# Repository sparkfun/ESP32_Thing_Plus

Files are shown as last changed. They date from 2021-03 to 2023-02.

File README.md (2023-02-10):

SparkFun ESP32 Thing Plus
========================================

SparkFun ESP32 Thing Plus (https://www.sparkfun.com/products/15663)

[*SparkFun ESP32 Thing Plus (WRL-15663)*](https://www.sparkfun.com/products/15663)

The [SparkFun ESP32 Thing Plus](https://www.sparkfun.com/products/15663) is a comprehensive development platform for [Espressif's ESP32](https://espressif.com/en/products/hardware/esp32/overview). Like the 8266 and ESP32 Thing, the ESP32 Thing Plus is a **WiFi**-compatible microcontroller with support for **Bluetooth low-energy** (i.e BLE, BT4.0, Bluetooth Smart), a Qwiic adapter, and 21 I/O pins. Add to that a rich set of peripherals ranging from capacitive touch sensors, SD card interface, Ethernet, high-speed SPI, UART, I2S and I<sup>2</sup>C.

Upgraded and easy to use, the Esp32 Thing Plus will help make it the foundation of IoT and connected projects for many years to come.

Repository Contents
-------------------

* **/Hardware** - Eagle design files (.brd, .sch)
* **/Production** - Production panel files (.brd)

Documentation
--------------
* **[Hookup Guide](https://learn.sparkfun.com/tutorials/esp32-thing-plus-hookup-guide)** - Basic hookup guide for the ESP32 Thing Plus.
* **[SparkFun Fritzing repo](https://github.com/sparkfun/Fritzing_Parts)** - Fritzing diagrams for SparkFun products.
* **[SparkFun Graphical Datasheets](https://github.com/sparkfun/Graphical_Datasheets)** -Graphical Datasheets for various SparkFun products.

Product Versions
----------------
* [WRL-15663](https://www.sparkfun.com/products/15663)- v2.0, Slight hardware update that includes a 10&ohm; series resistor between VUSB and CP2102
* [WRL-14689](https://www.sparkfun.com/products/14689)- v1.0, Initial Release

License Information
-------------------

This product is _**open source**_! 

Please review the LICENSE.md file for license information. 

If you have any questions or concerns on licensing, please contact technical support on our [SparkFun forums](https://forum.sparkfun.com/viewforum.php?f=152).

Distributed as-is; no warranty is given.

- Your friends at SparkFun.

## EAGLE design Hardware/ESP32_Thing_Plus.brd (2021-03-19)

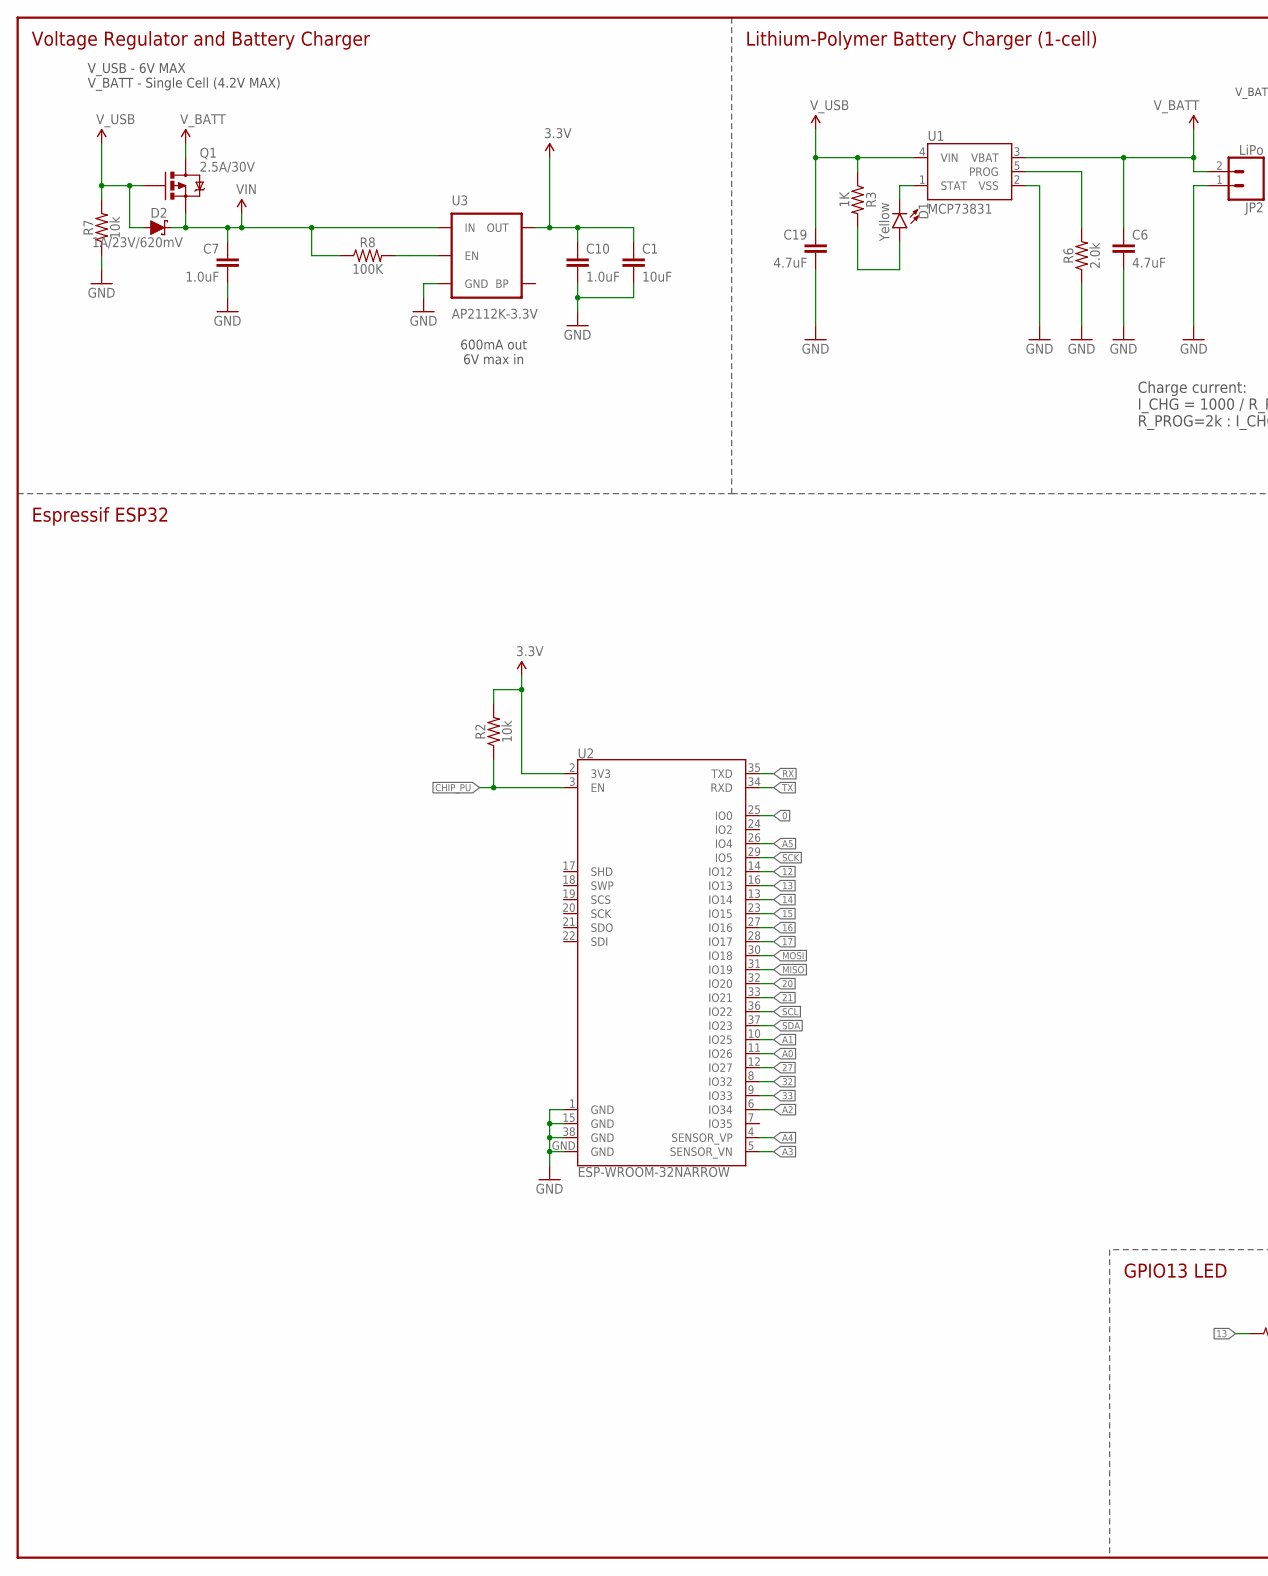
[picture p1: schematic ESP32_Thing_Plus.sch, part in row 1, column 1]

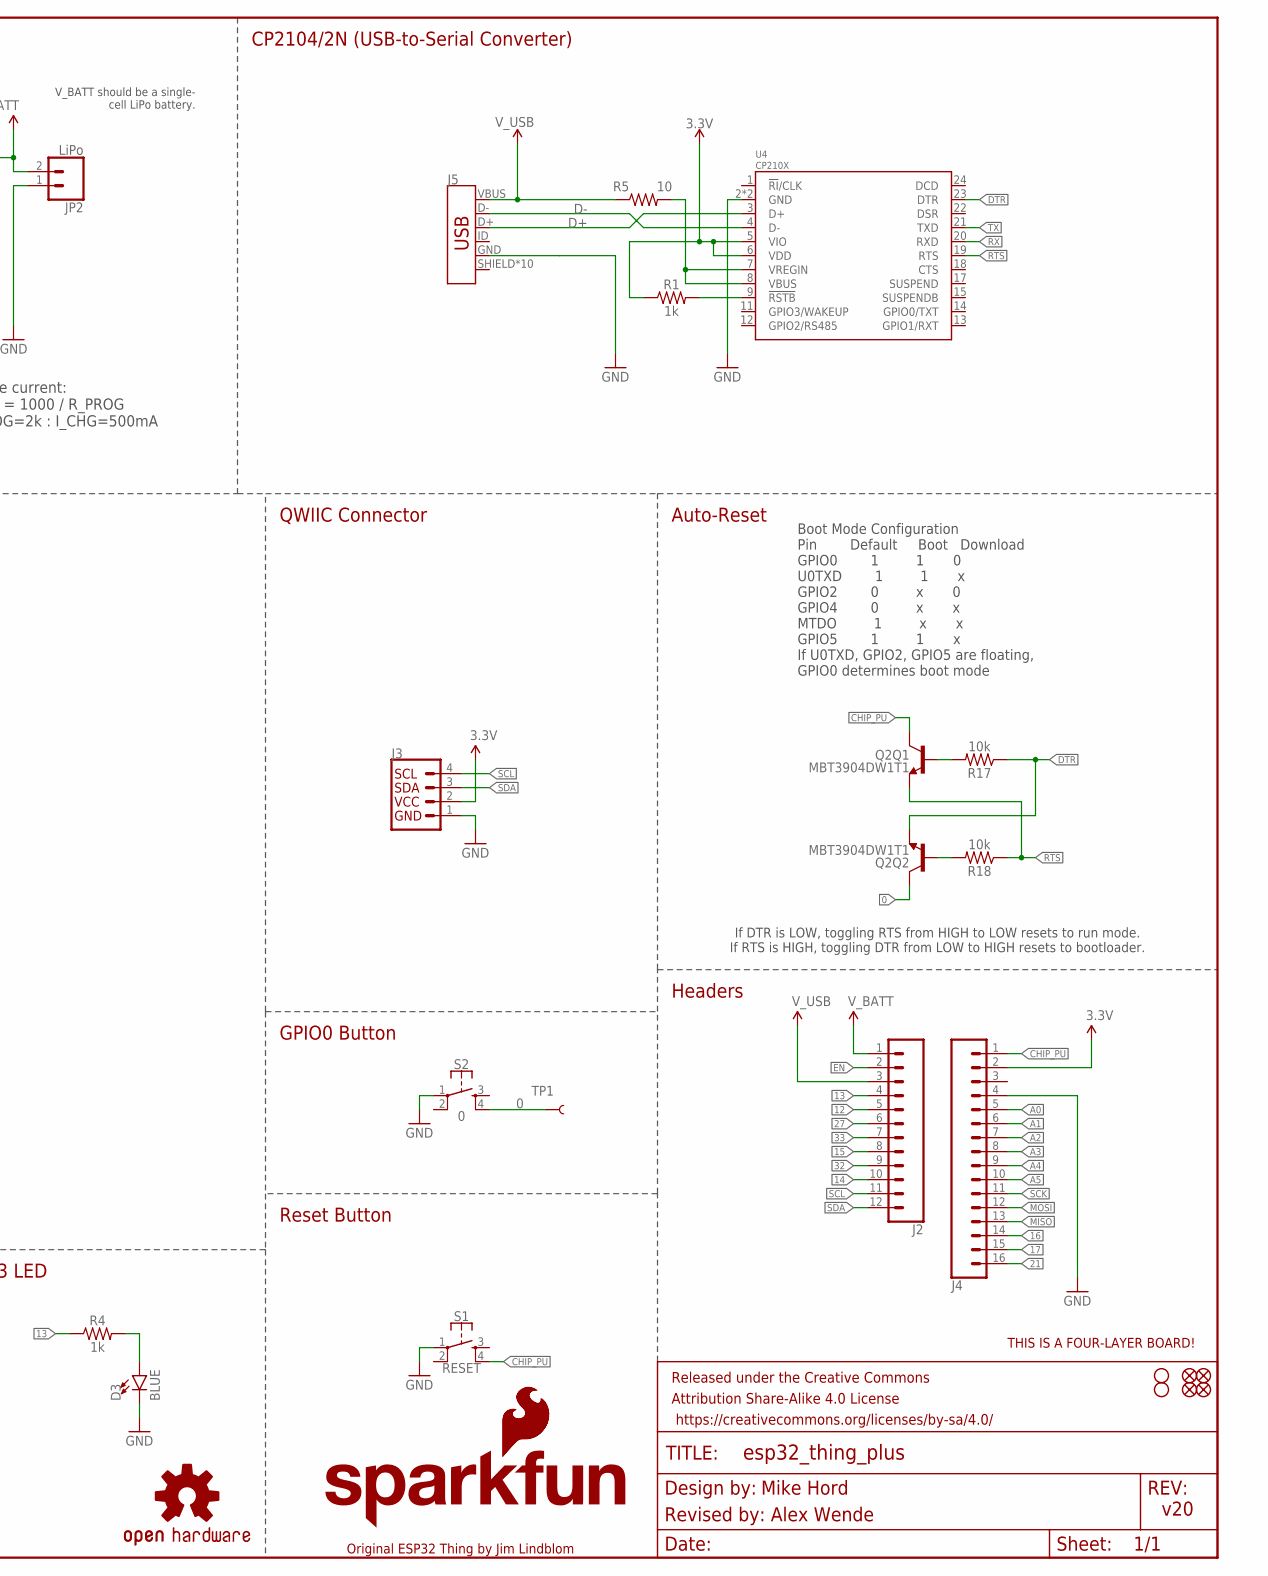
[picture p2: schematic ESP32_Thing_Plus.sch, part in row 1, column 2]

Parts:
C1: 10uF; 0603
C6, C19: 4.7uF; 0603
C7: 1.0uF; 0603
C10: 1.0uF; 0402
D1: Yellow; LED-0603
D2: 1A/23V/620mV; SOD-323
D3: BLUE; LED-0603
FD1, FD2, FD3, FD4: FIDUCIALUFIDUCIAL; FIDUCIAL-MICRO
FRAME1: FRAME-LEDGER; CREATIVE_COMMONS
H1, H2: STAND-OFFTIGHT; STAND-OFF-TIGHT
J2: CONN_12SM_SQ_NO_SILK; 1X12_SM_SQ_NOSILK
J3: QWIIC_CONNECTORJS-1MM; 1X04_1MM_RA
J4: CONN_161X16_SM_SQ_NOSILK; 1X16_SM_SQ_NOSILK
J5: USB_MICRO-B_HALF_PTH_MILL; USB-MICROB-PTH-MILL
JP2: LiPo; JST-2-SMD
LOGO1: SFE_LOGO_FLAME.1_INCH; SFE_LOGO_FLAME_.1
LOGO2: OSHW-LOGOMINI; OSHW-LOGO-MINI
LOGO3: SFE_LOGO_NAME_FLAME.1_INCH; SFE_LOGO_NAME_FLAME_.1
LOGO4: FOUR_LAYER_WARNING
Q1: 2.5A/30V; SOT23-3@1
Q2: MBT3904DW1T1; SC70-6
R1, R4: 1k; 0603
R2, R7, R17, R18: 10k; 0603
R3: 1K; 0603
R5: 10; 0603
R6: 2.0k; 0603
R8: 100K; 0402
S1: RESET; TACTILE_SWITCH_SMD_4.6X2.8MM
S2: 0; TACTILE_SWITCH_SMD_4.6X2.8MM
TP1: TEST-POINTTP_15TH_THRU; TP_15TH
U1: MCP73831; SOT23-5
U2: ESP-WROOM-32NARROW; ESP-WROOM-32-NARROW
U3: AP2112K-3.3V; SOT23-5
U4: CP210X; QFN24

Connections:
0: Q2.6 (C), S2.4, TP1.P$1, U2.25 (IO0)
3.3V: C1.1, C10.1, J3.2, J4.2, R1.1, R2.2, U2.2 (3V3), U3.5 (OUT), U4.5 (VIO), U4.6 (VDD)
12: J2.5, U2.14 (IO12)
13: J2.4, R4.1, U2.16 (IO13)
14: J2.10, U2.13 (IO14)
15: J2.8, U2.23 (IO15)
16: J4.14, U2.27 (IO16)
17: J4.15, U2.28 (IO17)
20: U2.32 (IO20)
21: J4.16, U2.33 (IO21)
27: J2.6, U2.12 (IO27)
32: J2.9, U2.8 (IO32)
33: J2.7, U2.9 (IO33)
A0: J4.5, U2.11 (IO26)
A1: J4.6, U2.10 (IO25)
A2: J4.7, U2.6 (IO34)
A3: J4.8, U2.5 (SENSOR_VN)
A4: J4.9, U2.4 (SENSOR_VP)
A5: J4.10, U2.26 (IO4)
CHG: D1.C, U1.1 (STAT)
CHIP_PU: J4.1, Q2.3 (C), R2.1, S1.4, U2.3 (EN)
D+: J5.D+, U4.3 (D+)
D-: J5.D-, U4.4 (D-)
DTR: Q2.1 (E), R17.1, U4.23 (DTR)
EN: J2.2, R8.2, U3.3 (EN)
GND: C1.2, C6.2, C7.2, C10.2, C19.2, D3.C, J3.1, J4.4, J5.GND, JP2.1 (2), R6.1, R7.1, S1.1, S2.1, U1.2 (VSS), U2.1 (GND), U2.15 (GND), U2.38 (GND), U2.GND, U3.2 (GND), U4.2 (GND), U4.PAD (GND)
MISO: J4.13, U2.31 (IO19)
MOSI: J4.12, U2.30 (IO18)
unnamed: R1.2, U4.9 (!RSTB)
unnamed: D3.A, R4.2
unnamed: R5.2, U4.7 (VREGIN), U4.8 (VBUS)
unnamed: Q2.5 (B), R17.2
unnamed: Q2.2 (B), R18.2
unnamed: R6.2, U1.5 (PROG)
unnamed: D1.A, R3.2
RTS: Q2.4 (E), R18.1, U4.19 (RTS)
RX: U2.35 (TXD), U4.20 (RXD)
SCK: J4.11, U2.29 (IO5)
SCL: J2.11, J3.4, U2.36 (IO22)
SDA: J2.12, J3.3, U2.37 (IO23)
TX: U2.34 (RXD), U4.21 (TXD)
VIN: C7.1, D2.C, Q1.2 (S), R8.1, U3.1 (IN)
V_BATT: C6.1, J2.1, JP2.2 (1), Q1.3 (D), U1.3 (VBAT)
V_USB: C19.1, D2.A, J2.3, J5.VBUS, Q1.1 (G), R3.1, R5.1, R7.2, U1.4 (VIN)

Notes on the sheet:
Boot Mode Configuration Pin Default Boot Download GPIO0 1 1 0 U0TXD 1 1 x GPIO2 0 x 0 GPIO4 0 x x MTDO 1 x x GPIO5 1 1 x If U0TXD, GPIO2, GPIO5 are floating, GPIO0 determines boot mode
CP2104/2N (USB-to-Serial Converter)
V_BATT should be a single- cell LiPo battery.
Charge current: I_CHG = 1000 / R_PROG R_PROG=2k : I_CHG=500mA
Voltage Regulator and Battery Charger
Lithium-Polymer Battery Charger (1-cell)
600mA out 6V max in
Auto-Reset
Espressif ESP32
Reset Button
Headers
v20
Original ESP32 Thing by Jim Lindblom
If DTR is LOW, toggling RTS from HIGH to LOW resets to run mode. If RTS is HIGH, toggling DTR from LOW to HIGH resets to bootloader.
QWIIC Connector
Mike Hord
GPIO13 LED
GPIO0 Button
Revised by: Alex Wende
V_USB - 6V MAX V_BATT - Single Cell (4.2V MAX)

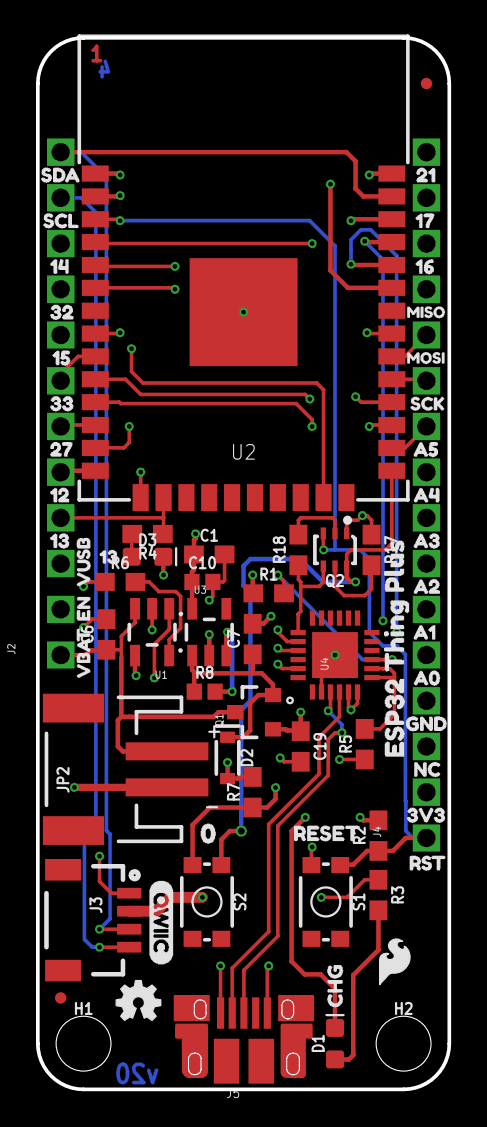
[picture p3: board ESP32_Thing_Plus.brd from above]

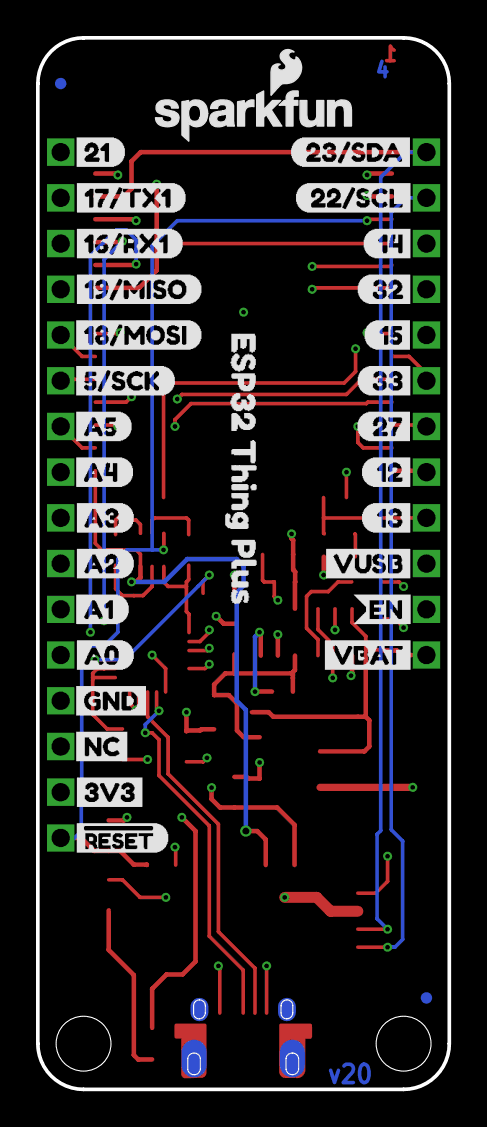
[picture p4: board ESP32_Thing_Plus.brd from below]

Board: 4 copper layers, 22.9 x 58.4 mm, 107 parts (32 on the bottom side), 43 nets.

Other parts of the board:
U$1: #RESET0
U$2: 3V31
U$3: 1323
U$4: 1417
U$5: 1519
U$6: 16#RX11
U$7: 17#TX10
U$8: 121
U$9: 210
U$10: 2721
U$11: 3218
U$12: 3320
U$13: A03
U$14: A14
U$15: A25
U$16: A36
U$17: A47
U$18: A58
U$19: EN26
U$20: GND2
U$21: 22#SCL1
U$22: 23#SDA0
U$23: QWIIC27
U$27: VBAT25
U$28: VUSB24
U$29: SDA1
U$30: SCL0
U$31: 142
U$32: 323
U$33: 154
U$34: 335
U$35: 276
U$36: 127
U$37: 138
U$38: 219
U$39: 1710
U$40: 1611
U$41: A515
U$42: A416
U$43: A317
U$44: A218
U$45: A119
U$46: A020
U$47: SCK20
U$48: GND21
U$49: NC22
U$50: VUSB8
U$51: EN9
U$52: VBAT10
U$53: 137
U$54: MISO0
U$55: MOSI1
U$56: CHG1
U$57: RESET0
U$58, U$65: ESP32_THING_PLUS0
U$59: ORDERING_INSTRUCTIONS
U$60: 3V323
U$61: RST24
U$62: 00
U$63: 5#SCK2
U$64: NC0
U$66: 18#MOSI1
U$67: 19#MISO0

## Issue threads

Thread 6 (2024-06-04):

High Leakage From VBAT to VBUS

DominicChm, 2024-06-04:
This issue is spawned from the Sparkfun forum post [here](https://forum.sparkfun.com/viewtopic.php?p=249708#p249708).

I've noticed the [Thing Plus USB-C](https://www.sparkfun.com/products/20168) has an issue with high leakage from VBATT to VBUS when only the battery is connected. From testing I've done on my own board, the issue appears to be that D4  has extremely poor reverse leakage (along the lines of the [Infineon BAT60A](https://www.infineon.com/dgdl/Infineon-BAT60ASERIES-DS-v01_01-en.pdf?fileId=db3a304313d846880113def70c9304a9)) which allows a non-negligible amount of current to flow through R7 when on battery.

<details>
  <summary>Schematic</summary>

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

</details>

On my board, this results in VBUS being pulled to 2.5V when on battery power when it really should be ~0V. Given the 10K pulldown on this rail, it seems about 250uA is reverse leaking through the diode. The ESP32's deep sleep current is specced at ~10uA, so this leakage represents an obstacle to battery-powered projects.

This issue also prevents effectively recognizing when power is coming from USB vs when it's coming from battery b/c the rail never drops low enough to be registered as a digital LOW by the ESP32 (.25v). In my application this prevents me from setting the ESP to wake from deep sleep when USB power is supplied. I've mitigated by adding a 500ohm resistor to pull the rail low harder but I really wish this wasn't a problem in the first place.

Whatever diode is in the BOM really ought to be replaced with one that has a better reverse leakage spec. It looks like there's probably enough space on the PCB to even include one with a larger package which should allow the existing spec to be met without the reverse leakage problem.

DominicChm, 2024-06-04:
Posted to the wrong board repo, moved issue here:

https://github.com/sparkfun/SparkFun_Thing_Plus_ESP32_WROOM_C/issues/3

Closed 2024-06-04.

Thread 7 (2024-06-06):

"SPARKFUN ESP32 THING" ISSUE WITH ESPRESSIF VERSION 3.0.0 - CORE CLOCK INCORRECT FREQUENCY?

dfrodin, 2024-06-06:
This applies to the "Sparkfun ESP32 Thing" not the Thing Plus.

With the latest 3.0.0 rev of the espressif ESP32 library with the Arduino IDE there is an issue with several of the clocks or perhaps just the core clock.

I initialize the serial port to 115k baud in setup(). With the latest espressif library change I have to reduce the baud rate on the serial monitor to 74880 to get meaningful output. The ratio of those two values is 115200/74880 = 1.55.

I noticed that pressing the reset button on the "ESP32 Thing" produces the normal output of ...
ets Jul 29 2019 12:21:46
rst:0x1 (POWERON_RESET),boot:0x13 (SPI_FAST_FLASH_BOOT)
configsip: 0, SPIWP:0xee
clk_drv:0x00,q_drv:0x00,d_drv:0x00,cs0_drv:0x00,hd_drv:0x00,wp_drv:0x00
mode:DIO, clock div:1
load:0x3fff0030,len:1288
load:0x40078000,len:13872
load:0x40080400,len:4
ho 8 tail 4 room 4
load:0x40080404,len:3048
entry 0x40080590

This output arrives at the correct 115200 baud rather than the runtime baudrate of 74880.

If I output a message every 60,000 msec using the Arduino millis() function you should get a message output every minute.
This has worked in the past but now outputs a message every 1 min 33 seconds. The ratio of these values is also 93/60 = 1.55.

I haven't been able to reproduce these problems on a XIAO_ESP32C3 board.

I'm guessing that there is a missing configuration of the ESP32 core clock divider/multiplier setting that didn't get adjusted with all of the other changes made by espressif in the 3.0.0 release.

I'm unaware of what version/variant of the ESP32 is on the "Sparkfun ESP32 THING".
Feel free to ask if you need details on any particulars I can provide.

dfrodin, 2024-06-10:
This chunk of code was pulled out of the Arduino examples/eps32/serial/Serial_All_CPU_Freqs.ino produces different
results depending on which esp32 board library is used.

uint32_t Freq = getCpuFrequencyMhz();
Serial.print("CPU Freq = ");
Serial.print(Freq);
Serial.println(" MHz");
Freq = getXtalFrequencyMhz();
Serial.print("XTAL Freq = ");
Serial.print(Freq);
Serial.println(" MHz");
Freq = getApbFrequency();
Serial.print("APB Freq = ");
Serial.print(Freq);
Serial.println(" Hz");

For the 2.0.17 version it produces ...
CPU Freq = 240 MHz
XTAL Freq = 26 MHz
APB Freq = 80000000 Hz

For the 3.0.1 version it produces ...
CPU Freq = 240 MHz
XTAL Freq = 40 MHz
APB Freq = 80000000 Hz

I would guess that the XTAL frequency is a hardcoded value defined in the board code. And even though the 3.0.1 version reports the CPU Freq as 240MHz it might be 160MHz.

PaulZC, 2024-06-11:
Hi Dave (@dfrodin ),

Many thanks for digging into this.

We haven't seen the same issue on other ESP32 boards - but they usually use ESP32 modules with the crystal built-in. On the Thing, the XTAL is 26MHz and is 'external' to the ESP32-D0WDQ6-V3 processor:

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

I suspect v3.0.0 of the core isn't detecting the XTAL frequency correctly, or is defaulting to the wrong value.

This code is relevant:

https://github.com/espressif/esp-idf/blob/8760e6d2a7e19913bc40675dd71f374bcd51b0ae/components/esp_hw_support/port/esp32/rtc_clk.c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

It might be possible to correct the XTAL frequency by calling ```rtc_clk_xtal_freq_update((soc_xtal_freq_t)26);``` ?

I don't have a Thing here... Could you please set Core Debug Level to Verbose and give this a try:

```
#include "soc/rtc.h"

void setup() {
  delay(1000);

  rtc_clk_xtal_freq_update((rtc_xtal_freq_t)26);

  Serial.begin(115200);
  Serial.println("Hello world");
}

void loop() {
}
```

Best wishes,
Paul

dfrodin, 2024-06-11:
Paul,
Thanks for your response.
I'm using Arduino IDE ver 1.8.19. The verbose options for it are for "compilation" and/or "upload".
Was the "set Core Debug Level to Verbose" request a setting in the ver 2.x IDE?

I added a call to getXtalFrequencyMhz() which shows the transition from 40MHz to 26Mhz. It had no impact on the
serial baud rate or the millis() timer.
If the rtc_xtal_freq gets updated, doesn't a call need to be made to do the calculations/configuration of the divider/multiplers to get to 240MHz from 26MHz rather than 40MHz?

PaulZC, 2024-06-11:
Hi Dave,

The Verbose option is under Tools \ Core Debug Level (in the "Boards" section).

So, no magic wand... That's a shame. I tried the code on a ESP32 Thing Plus C and it didn't change the baud rate either... I was hoping it might work on the Thing, but I'm not very surprised it isn't... I'll take another look at this tomorrow. We might need to ask Espressif for advice and/or a fix.

More later,
Paul

dfrodin, 2024-06-11:
Paul,
You nailed it so go ahead and take the rest of the day off.

this ...
   rtc_clk_xtal_freq_update((rtc_xtal_freq_t)26);
   rtc_clk_cpu_freq_set_xtal();

produces this result...
  CPU Freq = 26 MHz
  XTAL Freq = 26 MHz
  APB Freq = 26000000 Hz

then...
   setCpuFrequencyMhz(240);

produces...
  CPU Freq = 240 MHz
 XTAL Freq = 26 MHz
 APB Freq = 80000000 Hz

with the 3 calls from above the baud rate is correct at 115200 and the millis() timer is dead on.

I guess espressif should be made aware that there's some sort of bug in their clock init code.
I'll add the xtal/clk init changes to my existing code and go on my merry way.
If I see any future updates from 3.0.1 version of the  espressif lib I'll remove the xtal/clk tweak to
see if it was fixed in the library.

Thanks for finding this work around for me.
Dave Frodin

PaulZC, 2024-06-12:
Issue opened here: https://github.com/espressif/arduino-esp32/issues/9837

PaulZC, 2024-06-13:
Resolved! Please see: https://github.com/espressif/arduino-esp32/pull/9844

I'll leave this open until the fix is built into a arduino-esp32 Release Candidate

dfrodin, 2024-06-24:
PaulZC,
I've retested with the 3.0.2 version of the ESP32 library and everything is behaving correctly. Thanks for your efforts.

PaulZC, 2024-06-25:
Thanks Dave. Closing...

emilfihlman, 2024-09-29:
Is this supposed to be working now?
I'm using the latest nightly and running into this.

emilfihlman, 2024-09-29:
Initial findings:

So there was a patch, but a) it didn't patch esp32thing**_plus**, just esp32thing, ie esp32thing_plus is missing

`#define F_XTAL_MHZ 26  //SparkFun ESP32 Thing has 26MHz Crystal`
in variants/esp32thing_plus/pins_arduino.h

Secondly it still doesn't work, even though I've closed and opened and cleared /tmp/arduino etc many times for some reason and compiled and upload many times.

emilfihlman, 2024-09-29:
According to the datasheet (ESP32-WROOM-32D), this device should have 40MHz crystal, yet it definitely outputs at 74880 when Serial.begin(115200) is set.

Even stranger: after upload the device outputs at 74880, but then on plug out and back in or pressing reset button results in the device outputting on 115200 :D

Even even stranger, the device also initially outputs on the correct frequency but then switches to the wrong one after _after_

The only code on the device is Arduino RMT.

emilfihlman, 2024-09-29:
Since the issue was supposed to have been fixed at the espressif arduino repo, I'm putting everything in that issue there for now instead to all three places.

https://github.com/espressif/arduino-esp32/issues/9837

emilfihlman, 2024-09-29:
Issue opened at https://github.com/espressif/arduino-esp32/issues/10388

Closed 2024-06-25.

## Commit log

2018-04-13 Initial changes to board design
    [ESP32_Thing_Plus.brd, ESP32_Thing_Plus.sch, esp32-thing.brd]
2018-04-19 Ready for qc review
    [ESP32_Thing_Plus.brd, ESP32_Thing_Plus.sch]
2018-04-19 Revised per QC double check
    [ESP32_Thing_Plus.brd, ESP32_Thing_Plus.sch]
2018-04-25 Replaced EOL 1.0uF cap with newer one
    [ESP32_Thing_Plus.brd, ESP32_Thing_Plus.sch]
2018-06-05 Feedback from review
    [ESP32_Thing_Plus.brd, ESP32_Thing_Plus.sch]
2018-06-06 Fixes after QC review
    [ESP32_Thing_Plus.brd, ESP32_Thing_Plus.sch]
2018-06-25 Changes from review, changed silk
    [ESP32_Thing_Plus.brd, ESP32_Thing_Plus.sch]
2018-06-27 Add prod_id to wroom module
    [ESP32_Thing_Plus.brd, ESP32_Thing_Plus.sch]
2018-08-14 v03 Changes
    -Updated size to 2.3x0.9in
    - Moved Qwiic connector to top
    - Adjusted inner layer copper pour
    - Cleaned up traces
    [ESP32_Thing_Plus.brd, ESP32_Thing_Plus.sch]
2018-08-20 V03 Changes Cont.
    - Removed battery voltage divider
    - Increased Board name silk on bottom
    - Added NC buzzard labels to unconnected header pin.
    - Added button to GPIO-0
    - Swapped battery pins to match lipo battery pins
    - Fixed missing pin connections on USB transceiver.
    [ESP32_Thing_Plus.brd, ESP32_Thing_Plus.sch]
2018-08-21 V03 QC Fixes
    - Replaced via on GPIO0 with test point via
    [ESP32_Thing_Plus.brd, ESP32_Thing_Plus.sch]
2018-12-13 v10
    -Updated silk to include pin numbers and seondary functions for SPI/I2C/UART
    -Remapped a couple outer pins to match board definitions file
    [ESP32_Thing_Plus.brd, ESP32_Thing_Plus.sch]
2018-12-13 v10 design review changes
    - Moved battery connector away from headers by 0.030"
    - Moved charge led and resistor away from standoff
    - Fixed silk on header pins 21 and 12
    [ESP32_Thing_Plus.brd, ESP32_Thing_Plus.sch]
2018-12-13 v10 design review changes cont.
    Fixed pin 1 marker on dual NPN transistor
    [ESP32_Thing_Plus.brd, ESP32_Thing_Plus.sch]
2018-12-17 v10 QC Fixes
    - Replaced drill hit with standoff
    - Added VCC range and battery type to schematic
    - Updated USB connector
    [ESP32_Thing_Plus.brd, ESP32_Thing_Plus.sch]
2019-08-02 v20
    Added 10ohm series resistor between VUSB and CP2102
    [ESP32_Thing_Plus.brd, ESP32_Thing_Plus.sch]
2019-08-20 Update ESP32_Thing_Plus.brd
    Updated Buzzard Labels
    [ESP32_Thing_Plus.brd]
2020-09-08 Updated USB to UART converter
    Updated shematic to indicate the USB to UART converter can be either the CP2104 or CP2102N
    [ESP32_Thing_Plus.brd, ESP32_Thing_Plus.sch]
2021-03-19 Updated Attributes
    Changed U2 Prod_ID from IC-13849 to IC-15676
    [ESP32_Thing_Plus.brd, ESP32_Thing_Plus.sch]

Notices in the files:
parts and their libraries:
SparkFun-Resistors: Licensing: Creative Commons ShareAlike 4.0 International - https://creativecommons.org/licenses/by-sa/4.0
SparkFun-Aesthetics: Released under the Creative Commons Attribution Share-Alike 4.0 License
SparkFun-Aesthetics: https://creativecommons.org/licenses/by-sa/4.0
